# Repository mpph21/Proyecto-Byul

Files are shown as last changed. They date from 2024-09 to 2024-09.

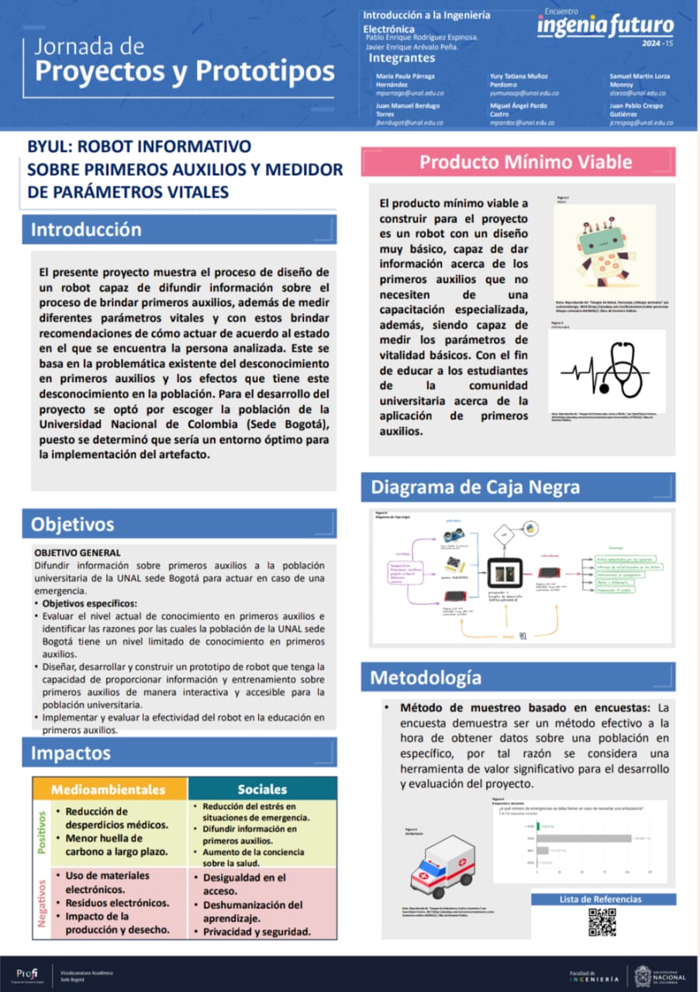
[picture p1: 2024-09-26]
poster.jpg

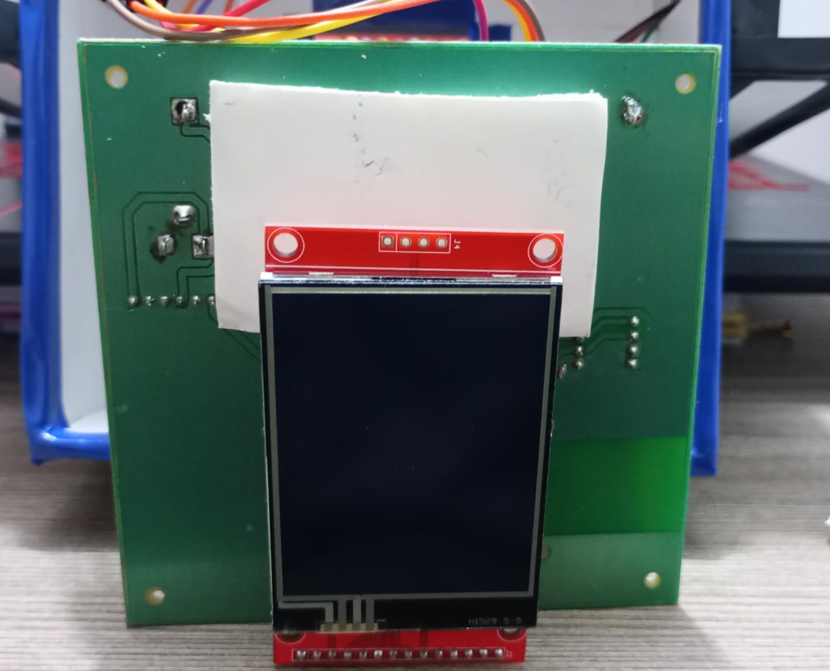
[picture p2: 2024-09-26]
ensamblaje_final.jpg

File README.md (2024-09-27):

# Proyecto-Byul
Robot capaz de difundir información sobre primeros auxilios, además de medir diferentes parámetros vitales.

*INTRODUCCIÓN*

El presente proyecto muestra el proceso de diseño de un robot capaz de difundir información sobre el proceso de brindar primeros auxilios, además de medir diferentes parámetros vitales y con estos brindar recomendaciones de cómo actuar de acuerdo al estado en el que se encuentra la persona analizada. Este se basa en la problemática existente del desconocimiento en primeros auxilios y los efectos que tiene este desconocimiento en la población. Para el desarrollo del proyecto se optó por escoger la población de la Universidad Nacional de Colombia (Sede Bogotá), puesto se determinó que sería un entorno óptimo para la implementación del artefacto.

*PRODUCTO MÍNIMO VIABLE*

El producto mínimo viable a construir para el proyecto es un robot con un diseño muy básico, capaz de dar información acerca de los primeros auxilios que no necesiten de una capacitación especializada, además, siendo capaz de medir los parámetros de vitalidad básicos. Con el fin de educar a los estudiantes de la comunidad universitaria acerca de la aplicación de primeros auxilios.

[Byul Encuentro Ingenia Futuro 2024-1S.pdf](https://github.com/user-attachments/files/17123102/Byul.Encuentro.Ingenia.Futuro.2024-1S.pdf)

VIDEO SUSTENTACIÓN https://drive.google.com/file/d/1y00nmVABIv68McBKW9m6ADhYE01oZToh/view?usp=sharing

VIDEO FUNCIONAMIENTO: https://youtu.be/uoFE4L-aYWc

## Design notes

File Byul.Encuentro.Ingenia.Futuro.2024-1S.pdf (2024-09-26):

## Introducción

## Objetivos

## Impactos

## Producto Mínimo Viable

## Diagrama de Caja Negra

## Metodología

# PON AQUÍ EL NOMBRE DE TU PROYECTO

Introducción a la Ingeniería Electrónica
Pablo Enrique Rodríguez Espinosa. Javier Enrique Arévalo Peña.

María Paula Párraga
Hernández
mparraga@unal.edu.co
Juan Manuel Berdugo
Torres
jberdugot@unal.edu.co

Yury Tatiana Muñoz
Perdomo
yumunozp@unal.edu.co
Miguel Ángel Pardo
Castro
mpardoc@unal.edu.co

Samuel Martin Lorza
Monroy
slorza@unal.edu.co
Juan Pablo Crespo
Gutiérrez
jcrespog@unal.edu.co

## BYUL: ROBOT INFORMATIVO SOBRE PRIMEROS AUXILIOS Y MEDIDOR DE PARÁMETROS VITALES

El presente proyecto muestra el proceso de diseño de un robot capaz de difundir información sobre el proceso de brindar primeros auxilios, además de medir diferentes parámetros vitales y con estos brindar recomendaciones de cómo actuar de acuerdo al estado en el que se encuentra la persona analizada. Este se basa en la problemática existente del desconocimiento en primeros auxilios y los efectos que tiene este desconocimiento en la población. Para el desarrollo del proyecto se optó por escoger la población de la Universidad Nacional de Colombia (Sede Bogotá), puesto se determinó que sería un entorno óptimo para la implementación del artefacto.

OBJETIVO GENERAL
Difundir información sobre primeros auxilios a la población universitaria de la UNAL sede Bogotá para actuar en caso de una emergencia.
- Objetivos específicos:
- Evaluar el nivel actual de conocimiento en primeros auxilios e identificar las razones por las cuales la población de la UNAL sede Bogotá tiene un nivel limitado de conocimiento en primeros auxilios.
- Diseñar, desarrollar y construir un prototipo de robot que tenga la capacidad de proporcionar información y entrenamiento sobre primeros auxilios de manera interactiva y accesible para la población universitaria.
- Implementar y evaluar la efectividad del robot en la educación en primeros auxilios.
- Método de muestreo basado en encuestas: La encuesta demuestra ser un método efectivo a la hora de obtener datos sobre una población en específico, por tal razón se considera una herramienta de valor significativo para el desarrollo y evaluación del proyecto.
- Reducción de
desperdicios médicos.
- Menor huella de
carbono a largo plazo.
- Uso de materiales
electrónicos.
- Residuos electrónicos.
- Impacto de la
producción y desecho.
- Reducción del estrés en
situaciones de emergencia.
- Difundir información en
primeros auxilios.
- Aumento de la conciencia sobre la salud.
- Desigualdad en el
acceso.
- Deshumanización del
aprendizaje.
- Privacidad y seguridad.

El producto mínimo viable a construir para el proyecto es un robot con un diseño
muy básico, capaz de dar
información acerca de los
primeros auxilios que no
necesiten | de | una
capacitación especializada, además, siendo capaz de
medir los parámetros de
vitalidad básicos. Con el fin de educar a los estudiantes
de | la | comunidad
universitaria acerca de la
aplicación | de | primeros
auxilios.

Figura 1
Robot

Nota. Reproducido de “Imagen de Robot, Personaje y Dibujos animados” por andresmdesign, 2023 (https://pixabay.com/es/illustrations/robot-personajedibujos-animados-8449206/). Obra de Dominio Público.

Figura 2
Estetoscopio

Nota. Reproducido de “Imagen de Estetoscopio, Icono y Médic,” por OpenClipart-Vectors, 2018 (https://pixabay.com/es/vectors/estetoscopio-icono-médica-3725131/). Obra de Dominio Publico.

Figura 3
Diagrama de Caja negra

Figura 4
Respuesta a encuesta

Figura 5
Ambulancia

Nota. Reproducido de “Imagen de Ambulancia, Coche y Isometrico” por OpenClipart-Vector, 2017 (https://pixabay.com/es/vectors/ambulancia-cocheisometrico-médico-2025651/). Obra de Dominio Publico

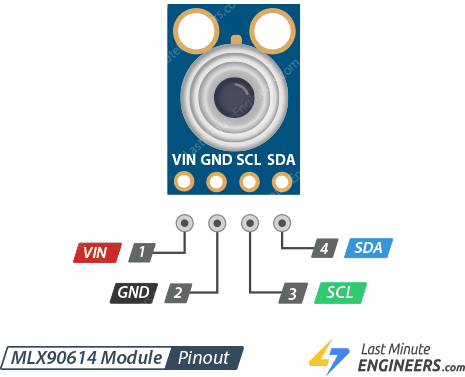
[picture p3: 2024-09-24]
Planeación Byul/InvestigacionComponentes/MLX90614-Module-Pinout.png

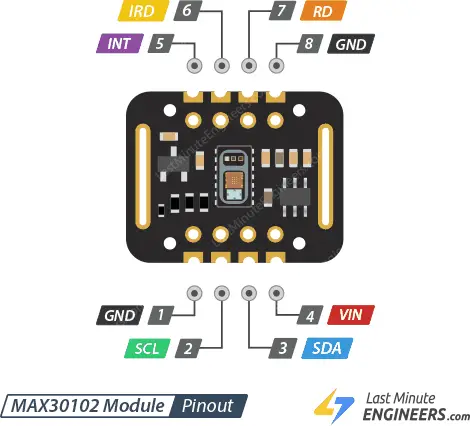
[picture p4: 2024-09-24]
Planeación Byul/InvestigacionComponentes/MAX30102-Module-Pinout.png

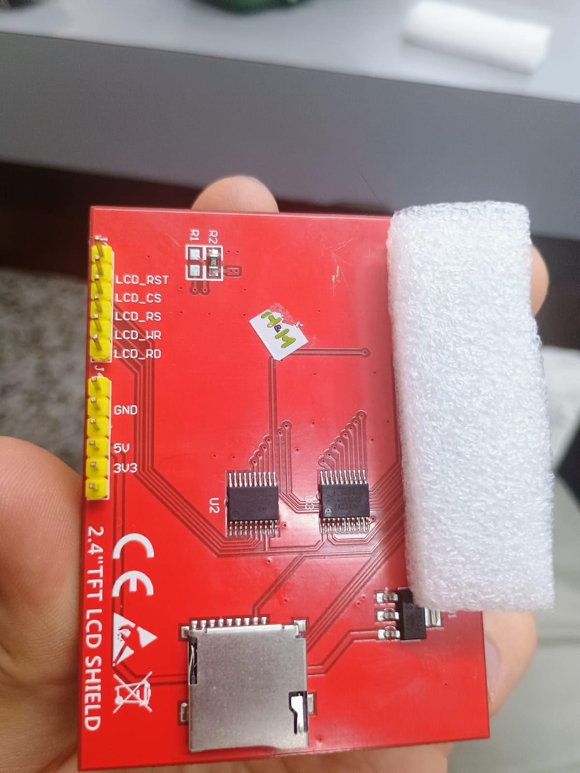
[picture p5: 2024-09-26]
pantallaLCD.jpg

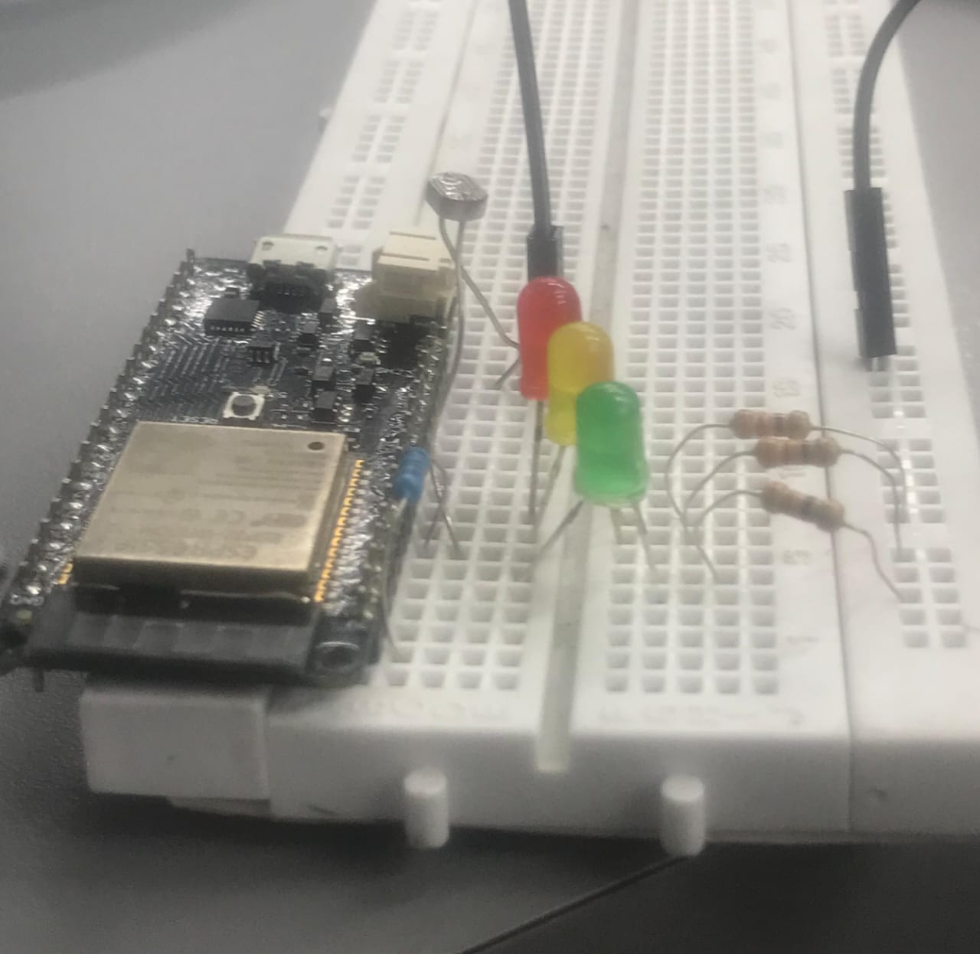
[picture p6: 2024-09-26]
ESP32 incidente.jpg

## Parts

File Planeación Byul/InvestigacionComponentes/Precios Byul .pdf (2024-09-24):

Análisis del Costo del Proyecto

El costo total del proyecto asciende a 264.000 COP, lo cual se considera razonable en función de los componentes empleados y las funcionalidades que ofrece. A continuación se presenta un análisis general de los costos:

### 1. Componentes Especializados

- Pantalla SPI TFT Touch: Con un costo de 77.000 COP, este componente es esencial para la interfaz del usuario, permitiendo la interacción táctil. Su precio es acorde al rango de productos similares en el mercado.
- Sensores: El proyecto incluye sensores de oxígeno, ritmo cardíaco y temperatura, con costos de 30.000 COP y 45.000 COP, respectivamente. Estos dispositivos tienen un precio competitivo en comparación con otras opciones disponibles, y son fundamentales para la medición de parámetros vitales.

### 2. Componentes Complementarios

- Elementos como el sensor de distancia (6.500 COP), la batería (8.000 COP), el PCB (25.000 COP) y otros accesorios (como cinta, jack, y fuente) tienen precios relativamente bajos. Estos componentes contribuyen a mantener los costos del proyecto controlados sin sacrificar funcionalidad.

### 3. Costo Total

- En conjunto, el costo total del proyecto es razonable para el nivel de tecnología involucrada. Los materiales utilizados permiten la creación de un sistema completo y funcional, que ofrece medición de parámetros vitales e integración de sensores en una interfaz gráfica interactiva.
Material | Precio
SPI TFT Touch | 77.000
Sensor oxigeno, ritomo cardiaco | 30.000
Sensor Distacia | 6.500
Sensor de temperatura | 45.000
Cerebro | 40.000
Foam Board | 16.000
PCB | 25.000
Bateria | 8.000
Modulo | 4.000
Fuente | 6.000
Cinta | 3.000
Jack | 500
Porta Bateria | 3.000
Total | 264.000

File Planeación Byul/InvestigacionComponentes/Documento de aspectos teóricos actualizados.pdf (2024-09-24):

# Robot Informativo Sobre Primeros Auxilios y Medidor de Parámetros Vitales

Juan Manuel Berdugo Torres, Juan Pablo Crespo Gutierrez, Maria Paula Parraga Hernández, Samuel Martin Lorza Monroy, Yury Tatiana Muñoz Perdomo, Miguel Angel Pardo Castro Universidad Nacional de Colombia Bogotá D.C., Colombia
jberdugot@unal.edu.co
jcrespog@unal.edu.co
mparraga@unal.edu.co
mpardoc@unal.edu.co
slorza@unal.edu.co
yumunozp@unal.edu.co
I. RESUMEN
El presente proyecto muestra el proceso de diseño de un robot capaz de educar sobre el proceso de brindar primeros auxilios, además de medir diferentes parámetros vitales y con estos brindar recomendaciones de cómo actuar de acuerdo al estado en el que se encuentra la persona analizada. Este se basa en la problemática existente del desconocimiento en primeros auxilios y los efectos que tiene este desconocimiento en la población. Teniendo en cuenta lo anterior, se realizarán varias estrategias que permitieron desarrollar la idea, en las cuales se encuentran, el análisis de la literatura y el método de muestreo basado en encuestas, lo cual permitirá contextualizar el problema. Para el desarrollo del proyecto se optó por escoger la población de la Universidad Nacional de Colombia (Sede Bogotá), puesto se determinó que sería un entorno óptimo para la implementación del artefacto. Finalmente, se tiene como objetivo que este robot logre educar a los estudiantes de la Universidad Nacional de Colombia frente a los primeros auxilios, ya que esto podría lograr que disminuyan algunos accidentes graves que puedan llegar a ocurrir en la universidad y si llegan a ocurrir que estos accidentes no sean tan graves.
II. INTRODUCCIÓN

En el ámbito universitario, la salud es un aspecto fundamental para el bienestar y la calidad de vida de las personas. Sin embargo, en ciertas facultades de la UNAL sede Bogotá existe un problema significativo relacionado con la falta de conocimiento sobre primeros auxilios, tales como; qué son, cómo y cuándo se deben ejecutar, y qué tipos existen. Esta carencia de conocimientos tiene un impacto negativo en la salud y seguridad individual y colectiva, limitando la capacidad de las personas para tomar decisiones acertadas en momentos de crisis.
Por tanto, la carencia de conocimientos en el área específica de los primeros auxilios es un problema complejo que se ve influenciado por diversos factores, tales como las desigualdades sociales y económicas, las deficiencias de la educación en salud general (y por tanto aún más en una rama de esta como lo son los primeros auxilios), la influencia de la cultura y los medios de comunicación, entre otros. Las consecuencias de esta dificultad son graves, viéndose que según Padilla (2022) “ver [1]” se pierden cerca de dos millones de vidas en el mundo solo por paros cardíacos evitables haciendo uso de los primeros auxilios, sin contar las heridas por quemaduras, los accidentes de trabajo o carretera etc.
Abordar esta problemática requiere un enfoque multifacético que involucre la implementación de estrategias de educación en los primeros auxilios, el fortalecimiento de la participación de la comunidad, y la investigación sobre las mejores prácticas para incrementar la conciencia sobre la importancia de los primeros auxilios.
Con este trabajo, se busca contribuir a la comprensión y el abordaje de la falta de conocimiento en primeros auxilios en la UNAL sede Bogotá, reconociendo su importancia y proponiendo una solución innovadora y accesible que pueda tener un impacto positivo en la salud y el bienestar de las personas.
A lo largo del proyecto, se explorarán los
fundamentos | teóricos | y | conceptuales
relacionados con el modelo sociocultural de la salud, los determinantes sociales de la salud, el enfoque de promoción de la salud, el modelo de creencias en salud y la teoría de la acción social, entre otros aspectos relevantes. Además, se analizarán estudios y datos específicos sobre el conocimiento en primeros auxilios que tiene la UNAL sede Bogotá, lo que permitirá comprender la magnitud y las implicaciones de este desafío.
Finalmente, | se | presentará | el
planteamiento del problema, la justificación, los objetivos y el producto mínimo viable propuesto, el cual consiste en un robot que brindará gran cantidad de información sobre los primeros auxilios a la población de la
UNAL | sede | Bogotá, | teniendo | como
complemento | a | lo anterior funciones
integradas para medir parámetros vitales.
III. ESTADO DEL ARTE
En la búsqueda constante de innovación en el campo de la salud y la tecnología, se han realizado diversos proyectos y desarrollos tecnológicos enfocados en brindar soluciones innovadoras para el monitoreo de la salud y la asistencia en primeros auxilios. Tanto en la Universidad Nacional de Colombia como en otras instituciones académicas, se han llevado a cabo iniciativas relevantes que sientan las bases para el proyecto propuesto y demuestran el compromiso con la innovación en este ámbito.
En el contexto de la Universidad Nacional de Colombia, destacan los siguientes trabajos:
Implementación de un sistema portátil de medición de signos vitales para pacientes con
requerimientos | de | medición | constante,
realizado por Velásquez (Universidad Nacional de Colombia, Sede Medellín, 2020) “ver [2]”. Siendo este un sistema portátil de medición de signos vitales que permite dar a conocer el estado del paciente, identificar anomalías médicas específicas y recomendarle cómo proceder en estos casos.
Diseño y construcción de un laboratorio portátil básico de física médica para primeros auxilios, construido por Calvo (Universidad Nacional de Colombia, Sede Bogotá, 2018), “ver [3]”. Este es un sistema parecido al que se propone, y consiste en la medición de señales emitidas por el cuerpo humano, que permite establecer contacto directo con el sistema operativo Android.
En | otras | instituciones, | se | han
desarrollado proyectos similares, como: Prototipo Electrónico que permita el Monitoreo de Signos Vitales como Alternativa de Apoyo en la Clasificación del Triage en Urgencias, hecho por Fajardo y Montoya (Universidad Católica de Colombia, 2020) “ver [4]”. Este proyecto propone el desarrollo tecnológico de un sistema que permita captar los signos vitales y conocer los síntomas que presenta el paciente de una manera rápida. Proyecto BioMed One creado por Vilar, Vasquez, Mejía y Bonilla (Universidad de los Andes, 2022) “ver [5]”. El proyecto propone instruir a las personas que no tengan conocimiento previo y estén cerca a un paciente con epilepsia que sufre convulsiones tónico-clónicas.

El proyecto que se propone es parecido a los anteriores mencionados, de manera que poseen funciones en común, como brindar información sobre primeros auxilios y evaluar signos vitales. Sin embargo, la innovación radica en la implementación de un robot capaz de realizar las tareas ya mencionadas, con un enfoque hacia la educación común en salud y su ubicación en un lugar accesible para la comunidad de la UNAL sede Bogotá. Por lo tanto, se plantea una solución innovadora con la aplicación de la Ingeniería Electrónica y el Desarrollo de la Tecnología, para la resolución de esta problemática.
IV. JUSTIFICACIÓN
El proyecto de desarrollar un robot capaz de tomar signos vitales y proporcionar información sobre primeros auxilios se justifica de manera contundente a partir de los resultados obtenidos en una encuesta realizada a más de 180 personas pertenecientes a la UNAL sede Bogotá. Esta encuesta reveló preocupantes niveles de desconocimiento en áreas clave de primeros auxilios y cuidado de la salud.
La encuesta empezó con dos preguntas generales, las cuales eran “¿Sabe que son los primeros auxilios?” y “¿Sabe cómo aplicar los primeros auxilios?”. En la primera pregunta, la mayoría de los encuestados, respondieron que sí sabían el concepto de primeros auxilios. Sin embargo, en la segunda pregunta, la mayor parte de las personas declararon que no conocían cómo aplicar los primeros auxilios. Posteriormente, se realizaron diez preguntas específicas sobre la aplicación de primeros auxilios, en las cuales ocho preguntas de las diez, fueron respondidas de manera errónea. Estos resultados son preocupantes, especialmente considerando que la encuesta se realizó a un pequeño porcentaje de la población total de la UNAL sede Bogotá. Si extendemos estos hallazgos al porcentaje total de la UNAL sede Bogotá, la situación podría ser aún más alarmante. La falta de preparación
en | primeros | auxilios | podría | tener
consecuencias graves en el bienestar de la
comunidad | universitaria | en | caso | de
emergencias médicas.
Ante estos resultados, el desarrollo de un robot que pueda proporcionar información precisa sobre signos vitales y primeros auxilios emerge como una solución viable y necesaria. Este robot no solo podría ayudar a educar a las
personas | sobre | cómo | responder
adecuadamente en emergencias médicas, sino que también podría intervenir directamente para proporcionar asistencia crucial mientras se espera la llegada de profesionales médicos.
V. PLANTEAMIENTO DEL
PROBLEMA
El problema a tratar en este proyecto es la carencia de los conocimientos y habilidades necesarios para actuar en caso de que se presente una emergencia médica de los estudiantes de la Universidad Nacional de Colombia Sede Bogotá. Para contextualizar el problema y englobarlo, se toma el hecho de que el conocimiento acerca de la salud en general es preocupante.
Con lo anterior, la falta de conocimientos en salud (y por tanto en primeros auxilios) puede atribuirse a diversos factores, como las barreras de acceso a la información, los pocos servicios de educación en salud, la falta de recursos, el nivel educativo, el nivel socioeconómico, la edad y el sexo, provocando que muchas situaciones de crisis (como convulsiones, paros cardiacos, quemaduras, entre otros.) terminan siendo de mayor gravedad de lo que pudieron haber sido. Tomando un ejemplo, en Colombia según el DANE la cifra de personas que murieron por infartos al miocardio en 2021 “ver [6]” fue de aproximadamente más de 47.621 mil personas. De esto se puede inferir que muchas de estas muertes se dieron porque el entorno cercano a estas personas no sabía que hacer en caso de emergencia, teniendo en cuenta que una gran parte de las personas en Colombia tiene una deficiencia en el uso y conocimiento de los primeros auxilios. Sabiendo lo anterior, se destaca la importancia de iniciar un proceso de enseñanza en primeros auxilios en la población de la universidad, puesto que estas personas son de fácil acceso y monitoreo para los investigadores, logrando expandirse en un futuro a zonas más alejadas de la capital, brindando así una herramienta que permite que una situación de emergencia de salud sea manejable y no terminando en un suceso fatal o una afectación grave a algún individuo.
Por lo anteriormente mencionado, nace la pregunta ¿Qué objeto electrónico se puede diseñar para difundir información a algunos miembros de la UNAL sede Bogotá sobre cómo hacer primeros auxilios?
VI. PREGUNTA PROBLEMA
¿Qué objeto electrónico se puede diseñar para difundir información a algunos miembros de la UNAL sede Bogotá sobre cómo hacer primeros auxilios?
VII. MARCO TEÓRICO
A. Modelo Sociocultural de la Salud Para comenzar el marco teórico, se debe hablar de cómo según Hernández, J et al (2017) “ver [7]” el sistema de salud colombiano general es uno de nivel intermedio basándonos en el modelo de determinantes sociales y ambientales de la OMS, lo que quiere decir que la salud en Colombia afecta y es afectada por el desarrollo social, económico y político de todo el país. Según este contexto, Hernández, J. et al (2017) dice que Colombia debe de cambiar de un sistema de enfoque “reactivo”, donde se espera hasta que alguien se enferme para actuar y que compromete el juicio de las personas (teniendo como
evidencia | la | encuesta | anteriormente
mencionada, donde muchos de los integrantes de la población desconocían cómo actuar frente a situaciones de crisis de salud), por uno más “preventivo”, donde se educa a las personas como “sujetos críticos” y se les enseñan distintas habilidades referentes al bienestar. Por lo anterior, se puede observar que un pequeño, pero necesario paso para esta transición puede ser el hecho de enseñar acerca de la ejecución de los distintos primeros auxilios a una porción de la población, como lo puede ser los estudiantes de la UNAL sede Bogotá.
B. Determinantes sociales de la salud
Los determinantes sociales de la salud (DSS) son las condiciones sociales en las que las personas viven y trabajan, y que influyen en su salud individual y colectiva. Estos determinantes incluyen:
Condiciones socioeconómicas: Ingreso, educación, empleo, vivienda.
Entorno físico: Acceso a agua potable, saneamiento básico, aire limpio.
Entorno social: Redes sociales, apoyo social, seguridad.
Acceso a servicios de salud: Calidad, disponibilidad, accesibilidad.
C. Modelo de creencias de salud: El Modelo de Creencias de Salud es una teoría utilizada en la investigación y la promoción de la salud la cual se basa en dimensiones como la susceptibilidad percibida y la seriedad percibida de las consecuencias de una enfermedad. Este modelo sigue siendo fundamental en la psicología de la salud para explicar los comportamientos relacionados con la salud y la prevención de enfermedades. Desde un enfoque a la población universitaria este modelo es útil para determinar cómo los estudiantes perciben una enfermedad o un problema y la seriedad de este, en el caso de los primeros auxilios, esto es importante al ver como actúa o que prioridad le da un estudiante a uno de estos casos.

D. Promoción de la salud
La promoción de la salud en la universidad es un aspecto fundamental para el bienestar integral de la comunidad estudiantil. A través de iniciativas que fomentan hábitos saludables, se busca no solo prevenir enfermedades, sino también promover un estilo de vida activo y equilibrado. Esto afecta positivamente a la vida estudiantil al mejorar el rendimiento académico y reducir el estrés. La universidad, como espacio de aprendizaje y crecimiento personal, tiene la responsabilidad de proporcionar recursos y programas que promuevan la salud física, mental y emocional de sus estudiantes. Desde la implementación de políticas de alimentación saludable hasta la organización de actividades deportivas y de bienestar, la promoción de la salud en la universidad contribuye significativamente a la formación de individuos más saludables y resilientes.
1) Líneas estratégicas de acción: Fortalecer los entornos saludables.
Facilitar | la | participación | y | el
empoderamiento de la comunidad.
2) Educación común en salud: La ECS se define como un proceso educativo que busca promover la salud y el bienestar de la población a través de la enseñanza de
conocimientos, | habilidades | y | actitudes
relacionados con la salud. Es un proceso continuo y permanente que se desarrolla a lo largo de toda la vida, en diferentes ámbitos como la familia, la escuela, la comunidad y el trabajo.
E. Teoría de la Acción Social
Según Wikipedia (2023) “ver [8]” se refiere a la acción o actividad, hecha de forma subjetiva u objetiva, que posee un propósito para quiénes la realizan, y por ende, genera consecuencias en la sociedad, con el fin de concientizar y adoptar prácticas. Por ejemplo, una acción llevada a cabo en una universidad, que impacte en la conducta de los integrantes de la comunidad universitaria.
1)Influencia Social: La manera como las personas influyen en los pensamientos, sentimientos y comportamientos de otros.
F. Teorías y conceptos electrónicos
1) Señales: Se definen como señales en el libro Tema I: Señales y sistemas (s.f.) “ver [9]” a todo aquello que contiene información sobre el comportamiento de un fenómeno físico, que se representan matemáticamente mediante el uso de una función dependiente de una (aunque pueden ser múltiples) variable independiente. Además, se dividen en dos tipos principales, las continuas y las discretas, que según Roig, I et al (2015) “Las señales continuas son aquellas cuya variable o variables independientes son continuas y pueden tomar cualquier valor real y por tanto esta señal está definida para sucesiones continuas de la variable independiente” (p. 10) “ver [10]”. Tomando en cuenta lo anterior, también define las señales discretas como “...son aquellas cuya variable o variables independientes sólo pueden tomar un conjunto de valores finito y por lo tanto el valor de la señal sólo está definido para ese conjunto de valores” (p. 11).
Sabiendo esto, se establece que el
componente | más | importante | para | el
procesamiento de señales es el análisis de Fourier, ya que permite conocer los componentes oscilatorios de las diferentes señales lo que a su vez ayuda a comprender cómo funcionan estas señales.
2) Sistemas embebidos: Según Perez (2009) Un sistema embebido es un sistema cuya función principal no es computacional, pero es controlado por un computador integrado “ver [11]”. Este computador puede ser un microcontrolador o un microprocesador. La palabra embebido implica que se encuentra dentro del sistema general, oculto a la vista, y forma parte de un todo de mayores dimensiones.
Desde esta perspectiva se entiende que un sistema embebido posee características que modelan su esencia, estas características son: funcionamiento específico puesto se ejecutan un programa específico de forma repetitiva, fuertes limitaciones puesto poseen diferentes prerrequisitos que a priori son bastantes limitantes, como el mantener un tamaño reducido, reactivos y tiempo real esto a que muchos sistemas embebidos reaccionan a diferentes estímulos externos.
3) | Comunicación | inalámbrica:
Según la Real academia de ingeniería “La comunicación inalámbrica es aquella que se realiza entre dos dispositivos que no están conectados por un cable físico sino que utilizan el espectro electromagnético” (párr. 2) “ver [12]”. Puesta esta definición, se comprende que el concepto más importante en la comunicación inalámbrica es el espectro electromagnético que Blázquez Prieto, J (2011) “ver [13]” define como el rango de frecuencias de las ondas electromagnéticas, capaces de propagarse por un espacio según su longitud de onda y frecuencia. Los rangos de frecuencia que más se utilizan son: infrarrojos, microondas, radiofrecuencia, luz ultravioleta y rayos x.
4) Circuitos: La teoría de circuitos representa gran relevancia, puesto que a partir de esta se construyen la mayoría de ramas de la ingeniería electrónica y eléctrica. Teniendo esto en cuenta, Ferro, G (2016) “ver [14]” define un circuito como la interconexión de
distintos | (aunque | repetibles) | aparatos
eléctricos, donde cada componente se reconoce como un elemento.
Basándose en lo anterior, Roig, I et al (2015) “ver [15]” dice que esta teoría está directamente relacionada con la física, porque la materia está compuesta por átomos que a su vez están compuestos por electrones, los cuales tienen una gran facilidad para moverse, por lo cual son los que permiten el transporte de la carga eléctrica. En resumen, un circuito es una red de senderos que transportan corrientes eléctricas.
5) | Semiconductores: | Los
semiconductores tienen una gran importancia en la electrónica actual, debido a que este material se usa en muchos campos de esta ingeniería, como por ejemplo en la transformación de un tipo de energía en otro y el de poder manipular la energía eléctrica para poder realizar operaciones lógicas.
Teniendo | en | cuenta | lo | dicho
anteriormente, en el documento Tema 3:
Semiconductores | 3.1 | Semiconductores
intrínsecos y dopados (s.f.) se explica que “Los semiconductores son sustancias cuya
conductividad oscila entre 10 | y
| | | −3 | 10
| | | | 3
Siemen/metro y cuyo valor varía bastante con la temperatura” (p. 1) “ver [16]”. A bajas
temperaturas | los | electrones | de | los
semiconductores se mantienen ligados a sus átomos y no pueden moverse por eso se comportan como aislantes, a temperaturas altas hay electrones que poseen suficiente energía térmica para que salten su enlace covalente a niveles energéticos superiores, comportándose como conductores.
6) Sistemas: Ludwing Von Bertalanffy “ver [21]” define los sistemas como aquel conjunto de elementos interrelacionados que hacen parte de hacen parte de una estructura organizada. Además de eso propone que un sistema no solo puede ser entendido como la agrupación de cada una de sus partes, sino que también hay que tener en cuenta cada una de las interacciones de sus componentes.
Teniendo | en | cuenta | lo anteriormente
mencionado, se entiende que si en un sistema hay un cambio de algunas de sus partes o de las relaciones entre sus partes este deja de funcionar o funciona de alguna otra forma. Desde la modularidad de sistemas jerárquicos aplicados en circuitos o sistemas complejos propuesta por Baldwin y Clark “ver [20]” se entiende que los sistemas que a priori se consideran complejos necesitan ser descompuestos en subsistemas que estos a su vez tienen una jerarquía donde se establecen funciones para cada subsistema.
Asimismo, Daniel Gajski y Robert Kuhn “ver [22]” le dan a los sistemas eléctricos y electrónicos un enfoque jerárquico con diferentes niveles de abstracción los cuales define como: comportamiento (descripción funcional), estructura (organización del sistema) y geometría (implementación física).
7) Información: Según Claude Shannon “ver [23]”, la información es una medida de la incertidumbre. Con base en esto, propone que la información específica el estado de un medio físico, el cual puede influir en otros estados. Desde esta perspectiva, la información se puede definir como aquello que reduce la incertidumbre. Shannon también introduce el concepto de entropía en su teoría, explicando que, a mayor entropía en un mensaje, se requerirá una mayor cantidad de información para transmitirlo de manera efectiva.
G. Visualización de parámetros
El presente marco teórico describe los fundamentos y componentes clave para el desarrollo de un robot asistente de salud capaz de monitorear parámetros vitales, proporcionar información sobre primeros auxilios y alertar sobre posibles accidentes o emergencias médicas. Este dispositivo robótico tiene como objetivo contribuir a la promoción de la salud y la seguridad dentro de la comunidad universitaria de la Universidad Nacional de Colombia.
1) Diagrama de caja negra: El diagrama de caja negra es un bosquejo del funcionamiento del dispositivo planteado, donde se evidencian las variables que obtiene el dispositivo, las entradas por las que recibe estas variables, los actuadores y salidas, que con base en las variables ejecutan las funciones que se describirán a lo largo del apartado de “Visualización de parámetros”. Así, se puede ver el diagrama de caja negra a continuación.

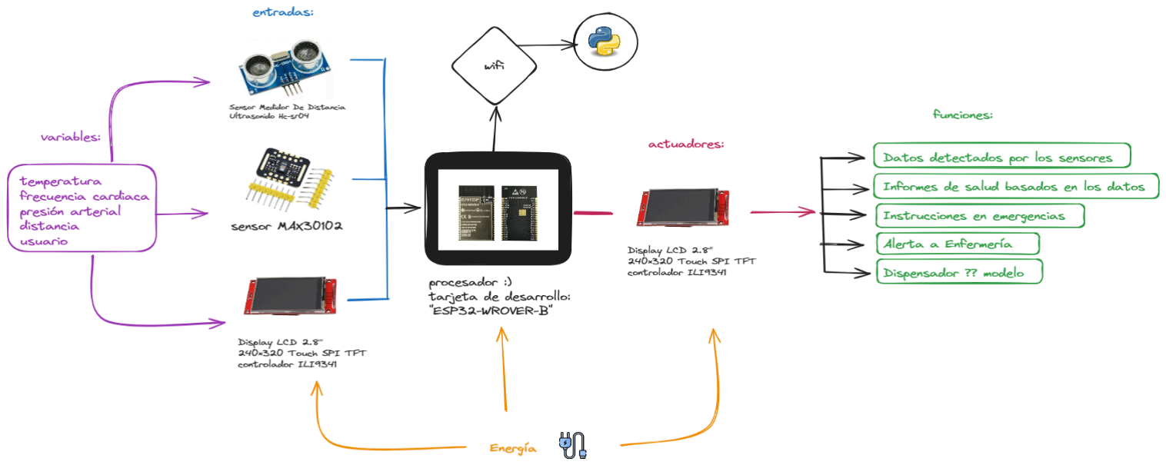
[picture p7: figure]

Fig. 1 Diagrama de caja negra del proyecto
2) Monitoreo de la salud con la medición de signos vitales: Frecuencia cardíaca, presión arterial y temperatura corporal mediante sensores específicos.
2.1) Generación de informes de salud personalizados basados en los datos recopilados:
3) Información sobre primeros auxilios: Base de datos integrada con
información | detallada | sobre | los
procedimientos a seguir en caso de diferentes tipos de accidentes o emergencias médicas.
3.1) Alerta de accidentes: Generación de alertas y notificaciones a servicios médicos o de emergencia a través de telegram.
4) Arquitectura del Sistema:
4.1) Subsistema de Adquisición de Datos: Sensores de frecuencia cardíaca, pulso y temperatura para la recopilación de datos vitales.
4.2) Subsistema de Procesamiento: Tarjeta de desarrollo ESP32 como unidad central de procesamiento.

Procesamiento y análisis de los datos recopilados por los sensores.
Generación de informes de salud y alertas de accidentes.
4.3) Subsistema de Interfaz de Usuario: Pantalla para la visualización de información.
Interacción con el usuario mediante botones, pantalla táctil.
4.4) Subsistema de Comunicación: Módulo de conectividad inalámbrica (WiFi, Bluetooth, etc.) para el envío de alertas y la actualización de la base de datos de primeros auxilios.
4.5) Software y Algoritmos: El software del robot se desarrollará utilizando el lenguaje de programación Python y se implementarán los siguientes algoritmos y funcionalidades:
- Adquisición y procesamiento de datos de sensores.
- Cálculo | de | parámetros | vitales
(frecuencia cardíaca, presión arterial, temperatura).
- Generación de informes de salud personalizados.
- Búsqueda | y | recuperación | de
información sobre primeros auxilios en la base de datos.
- Generación y envío de alertas a servicios médicos o de emergencia.
- Interfaz de usuario intuitiva y accesible.
VIII. HIPÓTESIS.
El proyecto propone un robot con un diseño básico como producto mínimo viable. Su objetivo principal será brindar información sobre primeros auxilios básicos y medir parámetros vitales como la frecuencia cardíaca y la presión arterial. Se espera que la implementación de este robot en la Universidad Nacional de Colombia, sede Bogotá, mejore la capacidad de respuesta de la comunidad universitaria ante situaciones de
emergencia | médica. | El | robot | podrá
proporcionar información oportuna sobre primeros auxilios y alertar a los servicios de emergencia de manera eficiente, optimizando el tiempo de respuesta y la atención médica en caso de una emergencia.
IX. PRODUCTO MÍNIMO
VIABLE
El producto mínimo viable a construir para el proyecto es un robot con un diseño muy básico, capaz de dar información acerca de los primeros auxilios que no necesiten de una capacitación especializada, además, siendo capaz de medir los parámetros de vitalidad básicos. Sin embargo, también se han pensado
funcionalidades | extras | para | la
complementación | del | robot, | y | serán
nombradas en el apartado de marco teórico.
A. Información a implementar al robot
Posteriormente, y gracias al análisis de la encuesta realizada, se definió que la información que contendrá el robot sería: el vendaje de heridas, los números de emergencias, la secuencia en la exploración primaria de una víctima, el control de hemorragias, cómo manejar quemaduras, la reanimación cardiopulmonar (RCP) y la maniobra de Heimlich. Así, toda la información mostrada fue extraída del
1) Vendaje de heridas:
Información y pasos para
colocar adecuadamente un
vendaje sobre una herida
2) Números de emergencia:
Los correctos números a
contactar en caso de
emergencia
3) Secuencia de exploración
primaria: | Secuencia | a

seguir | en | cualquier
accidente para identificar problemas y situaciones que supongan una amenaza para
la vida del paciente
4) Maniobra de Heimlich:
Esta maniobra está diseñada para ser usada ante el
atoramiento grave de una
persona, donde ésta es incapaz de expulsar el objeto extraño por si sola.
5) Reanimación
cardiopulmonar (RCP):
Maniobra a realizar cuando se
sufre | un | paro
cardiorespiratorio
6) Control de hemorragias: Tratamiento y pasos a seguir en caso de cortes o heridas que ocasionen un sangrado
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

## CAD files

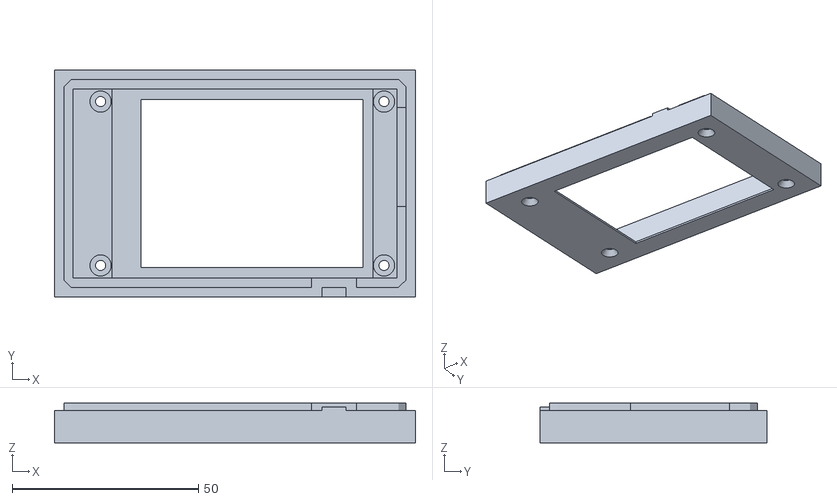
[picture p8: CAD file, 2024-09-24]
ByulCodigo/Librerias/micropython-ili9341-master/micropython-ili9341-master/sketchup/Top Cover.stl
96.9 x 60.8 x 10.7

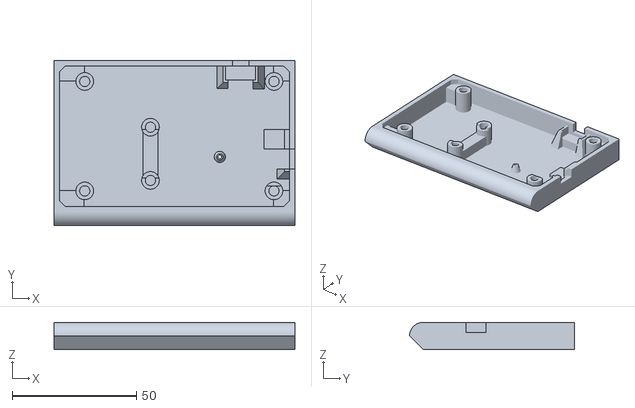
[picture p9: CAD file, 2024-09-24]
ByulCodigo/Librerias/micropython-ili9341-master/micropython-ili9341-master/sketchup/Case Bottom.stl
96.9 x 66.3 x 11.0

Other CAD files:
ByulCodigo/Librerias/micropython-ili9341-master/micropython-ili9341-master/sketchup/Case Bottom.skp
ByulCodigo/Librerias/micropython-ili9341-master/micropython-ili9341-master/sketchup/Top Cover.skp

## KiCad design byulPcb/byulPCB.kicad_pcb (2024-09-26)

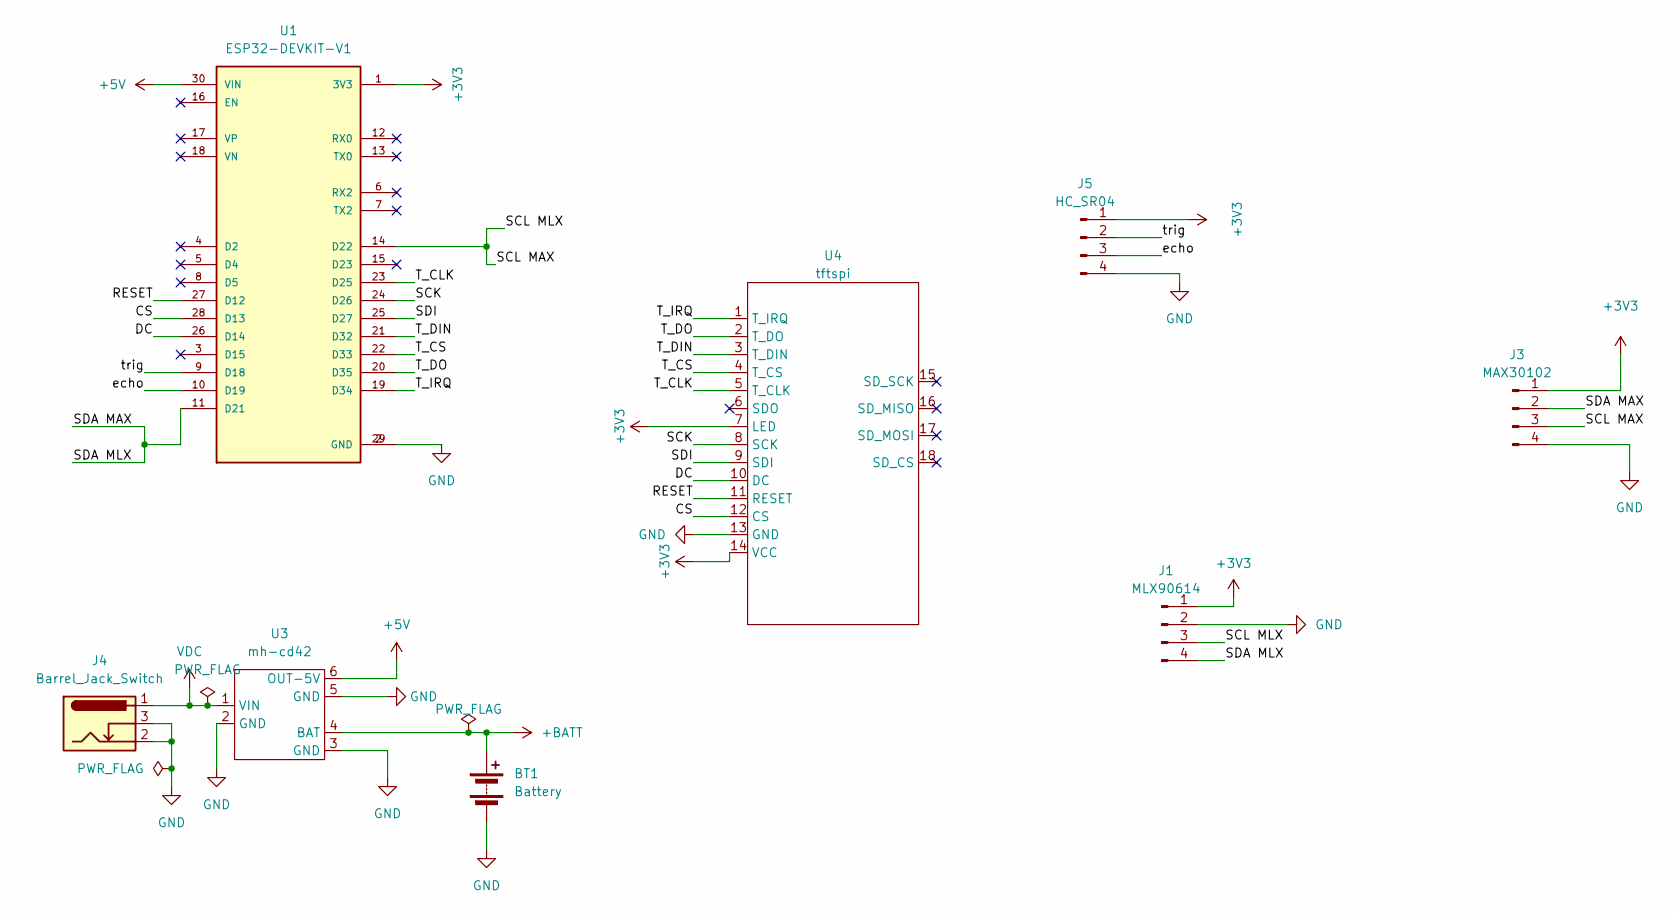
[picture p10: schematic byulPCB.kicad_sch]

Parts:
BT1: Battery; BatteryHolder_MPD_BH-18650-PC2
J1: MLX90614; PinHeader_1x04_P2.54mm_Vertical
J3: MAX30102; PinHeader_1x04_P2.54mm_Vertical
J4: Barrel_Jack_Switch; BarrelJack_Horizontal
J5: HC_SR04; PinHeader_1x04_P2.54mm_Vertical
U1: ESP32-DEVKIT-V1; MODULE_ESP32_DEVKIT_V1; PARTREV N/A
U3: mh-cd42
U4: tftspi

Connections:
+3V3: J1.1, J3.1, J5.1, U1.1 (3V3), U4.7 (LED), U4.14 (VCC)
+5V: U1.30 (VIN), U3.6 (OUT-5V)
+BATT: BT1.1 (+), U3.4 (BAT)
/CS: U1.28 (D13), U4.12 (CS)
/DC: U1.26 (D14), U4.10 (DC)
/RESET: U1.27 (D12), U4.11 (RESET)
/SCK: U1.24 (D26), U4.8 (SCK)
/SCL MAX: J1.3, J3.3, U1.14 (D22)
/SDA MAX: J1.4, J3.2, U1.11 (D21)
/SDI: U1.25 (D27), U4.9 (SDI)
/T_CLK: U1.23 (D25), U4.5 (T_CLK)
/T_CS: U1.22 (D33), U4.4 (T_CS)
/T_DIN: U1.21 (D32), U4.3 (T_DIN)
/T_DO: U1.20 (D35), U4.2 (T_DO)
/T_IRQ: U1.19 (D34), U4.1 (T_IRQ)
/echo: J5.3, U1.10 (D19)
/trig: J5.2, U1.9 (D18)
GND: BT1.2 (-), J1.2, J3.4, J4.2, J4.3, J5.4, U1.2 (GND), U1.29 (GND), U3.2 (GND), U3.3 (GND), U3.5 (GND), U4.13 (GND)
VDC: J4.1, U3.1 (VIN)

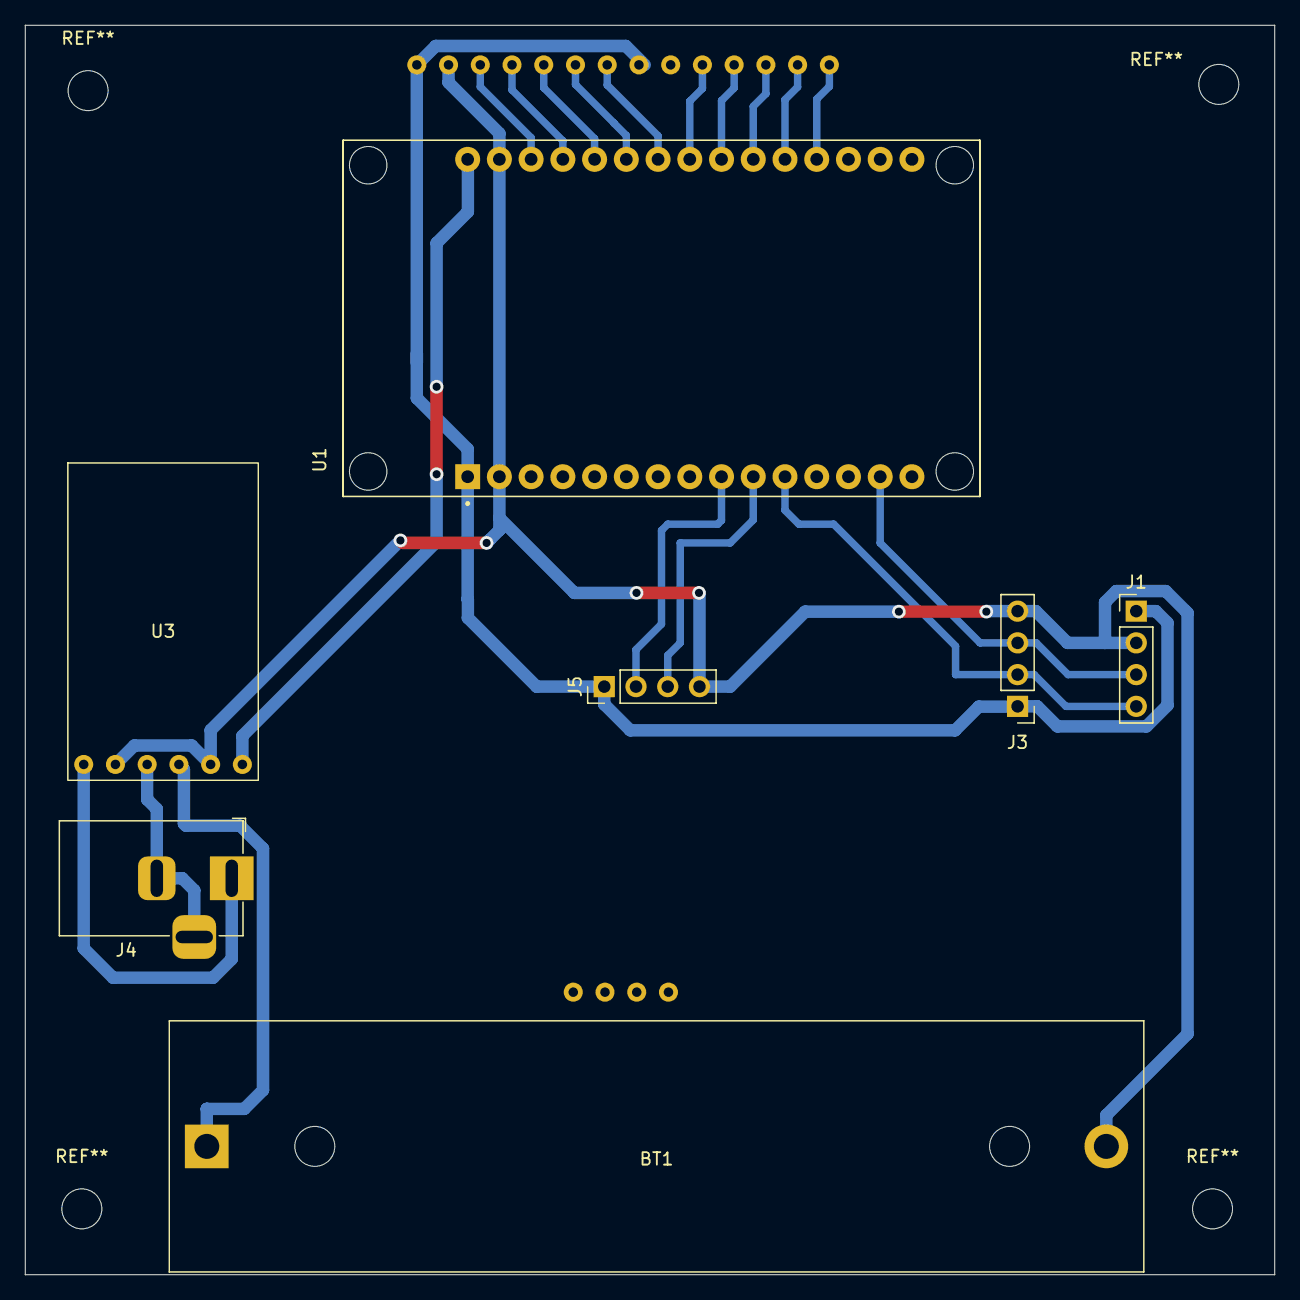
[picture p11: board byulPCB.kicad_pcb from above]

Board: 2 copper layers, 100.0 x 100.0 mm, 8 parts (1 on the bottom side), 19 nets.

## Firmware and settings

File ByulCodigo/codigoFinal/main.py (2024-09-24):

from ili9341 import Display, color565
from xpt2046 import Touch
from xglcd_font import XglcdFont
from machine import sleep, SoftI2C, Pin, SPI, time_pulse_us, idle
from utime import ticks_diff, ticks_us
import hrcalc
import time
from byul_funciones import ButtonDemo

def test():

    spi_display = SPI(1, baudrate=10000000, sck=Pin(26), mosi=Pin(27))
    display = Display(spi_display, dc=Pin(14), cs=Pin(13), rst=Pin(12))
    spi_touch = SPI(2, baudrate=1000000, sck=Pin(25), mosi=Pin(32), miso=Pin(35))
    touch = Touch(spi_touch, cs=Pin(33), int_pin=Pin(34))
    broadway_font = XglcdFont('fonts/Broadway17x15.c', 17, 15)


    demo = ButtonDemo(display, touch, broadway_font)
    try:
        demo.run()
    except KeyboardInterrupt:
        print("\nCtrl-C pressed. Cleaning up and exiting...")
    finally:
        display.cleanup()

test()         

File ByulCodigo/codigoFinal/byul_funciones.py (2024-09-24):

from ili9341 import Display, color565
from xpt2046 import Touch
from xglcd_font import XglcdFont
from max30102 import MAX30102, MAX30105_PULSE_AMP_MEDIUM
from machine import sleep, SoftI2C, Pin, SPI, time_pulse_us, idle
from utime import ticks_diff, ticks_us
import hrcalc
from mlx90614 import MLX90614
import time
from auxInfo import exploration_steps, burn_steps, steps,  choking_steps, rcp_steps, emergency_steps, hemorrhage_steps

class ButtonDemo(object):
    """Touchscreen button demo with multiple screens and custom font."""
    CYAN = color565(0, 255, 255)
    BLUE = color565(0, 0, 255)  # Fondo azul
    BLACK = color565(0, 0, 0)   # Texto negro
    LIGHT_BLUE = color565(173, 216, 230)  # Fondo celeste para los botones
    MAX_WIDTH = 220
    CHAR_WIDTH = 10

    def __init__(self, display, touch, font):
        """Initialize demo with buttons and custom font."""
        self.display = display
        self.touch = touch
        self.font = font
        self.main_menu = True  # Flag to know if we're in the main menu
        self.in_information_menu = False  # Track if in Information submenu
        self.current_step = 0  # Track the current step of the information
        self.current_page = 0
        
    
        self.draw_buttons()
        # Set touch interrupt handler
        self.touch.int_handler = self.touch_interrupt
        self.in_option_screen = False
        self.current_info_type = None
        self.sensors_initialized = False
        self.trigger = Pin(18, Pin.OUT)
        self.echo = Pin(19, Pin.IN)
        
        # Inicializamos la última distancia medida
        self.ultima_distancia = 500  # Inicializamos con un valor grande
        self.ultima_medicion_tiempo = time.time()
        
        
    def init_sensors(self):
        # Configuración de pines para el sensor de distancia
        self.trigger = Pin(18, Pin.OUT)
        self.echo = Pin(19, Pin.IN)
        
        # Configuración del sensor MAX30102
        i2c = SoftI2C(sda=Pin(21), scl=Pin(22), freq=100000)
        self.sensor_max = MAX30102(i2c=i2c)
        
        # Configuración del sensor MLX90614
        self.sensor_temp = MLX90614(i2c)
        
        # Verificar conexión del sensor MAX30102
        if self.sensor_max.i2c_address not in i2c.scan():
            print("Sensor MAX30102 no encontrado.")
        elif not self.sensor_max.check_part_id():
            print("ID de dispositivo I2C no corresponde a MAX30102 o MAX30105.")
        else:
            print("Sensor MAX30102 conectado y reconocido.")
        
        # Configuración del sensor MAX30102
        self.sensor_max.setup_sensor()
        self.sensor_max.set_sample_rate(400)
        self.sensor_max.set_fifo_average(16)
        self.sensor_max.set_active_leds_amplitude(MAX30105_PULSE_AMP_MEDIUM)
        self.sensor_max.set_led_mode(2)
        
        # Inicialización de variables para MAX30102
        self.MAX_HISTORY = 64
        self.history = []
        self.beats_history = []
        self.beat = False
        self.beats = 0
        self.counter = 0
        self.limit = 150
        self.temp_counter = 0
        
        # Buffers para almacenamiento de datos del MAX30102
        self.red_buf = []
        self.ir_buf = []
        
        # Tiempo de inicio
        self.t_start = time.ticks_us()
        
        # Umbral para detectar si no hay dedo en el sensor
        self.NO_FINGER_THRESHOLD = 100
        
        # Intervalo de medición de distancia
        self.DISTANCE_CHECK_INTERVAL = 5  # Segundos entre cada medición de distancia
        self.ultima_medicion_distancia = time.time()
        self.sensors_initialized = True

    def draw_buttons(self):
        """Draw the two main buttons on the screen using the custom font."""
        # Clear screen with cyan background
        self.display.clear(self.CYAN)

        # Draw Diagnostico button (button area: x=10, y=50 to x=210, y=90)
        self.display.fill_rectangle(10, 50, 200, 40, self.BLUE)
        self.display.draw_text(20, 60, 'Diagnostico:', self.font, self.BLACK, self.BLUE)

        # Draw Informacion button (button area: x=10, y=120 to x=210, y=160)
        self.display.fill_rectangle(10, 120, 200, 40, self.BLUE)
        self.display.draw_text(20, 130, 'Informacion:', self.font, self.BLACK, self.BLUE)

    def draw_information_menu(self):
        """Draw the information submenu with multiple options."""
        self.display.clear(self.BLUE)

        options = [
            
            'RCP',
            'Control de hemorragias',
            'Maniobra de Heimlich',
            'Vendaje de heridas',
            'Manejo de quemaduras',
            'Exploracion primaria',
            'Numeros de emergencia'
        ]
        
            # Define button dimensions and spacing
        button_height = 25  # Reduced height for buttons
        button_spacing = 10  # Spacing between buttons

        # Draw each option as a button
        for i, option in enumerate(options):
            y_position = 30 + i * (button_height + button_spacing)
            self.display.fill_rectangle(5, y_position, 228, button_height, self.LIGHT_BLUE)
            self.display.draw_text(7, y_position + 5, option, self.font, self.BLACK, self.LIGHT_BLUE)

        # Draw Atras button
        self.display.fill_rectangle(5, 30 + len(options) * (button_height + button_spacing), 228, button_height, self.LIGHT_BLUE)
        self.display.draw_text(80, 30 + len(options) * (button_height + button_spacing) + 5, 'Atras:', self.font, self.BLACK, self.LIGHT_BLUE)

    def draw_back_screen(self, message):
        """Draw the message and the back button on the screen."""
        # Clear screen with cyan background
        self.display.clear(self.CYAN)

        # Display the selected option message
        self.display.draw_text(10, 100, message, self.font, self.BLACK, self.CYAN)

        # Draw Atras button (button area: x=10, y=200 to x=210, y=240)
        self.display.fill_rectangle(10, 200, 200, 40, self.LIGHT_BLUE)
        self.display.draw_text(80, 210, 'Atras:', self.font, self.BLACK, self.LIGHT_BLUE)
        
    def paginate_text(self, text, max_width, max_lines):
        """Divide el texto en páginas, cada una con un máximo de líneas permitidas."""
        # Split the text by new lines
        paragraphs = text.split('\n')
        lines = []
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

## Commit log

2024-09-26 documentación kicad
    [byulPCB.kicad_pcb, byulPCB.kicad_sch]
2024-09-26 Add files via upload
    PCB interconectada
2024-09-26 Add files via upload
    Quema de la esp32
2024-09-26 Add files via upload
    Ensamblaje de los distintos componentes del prototipo para su presentación final.
2024-09-26 Add files via upload
    Compra de componentes
